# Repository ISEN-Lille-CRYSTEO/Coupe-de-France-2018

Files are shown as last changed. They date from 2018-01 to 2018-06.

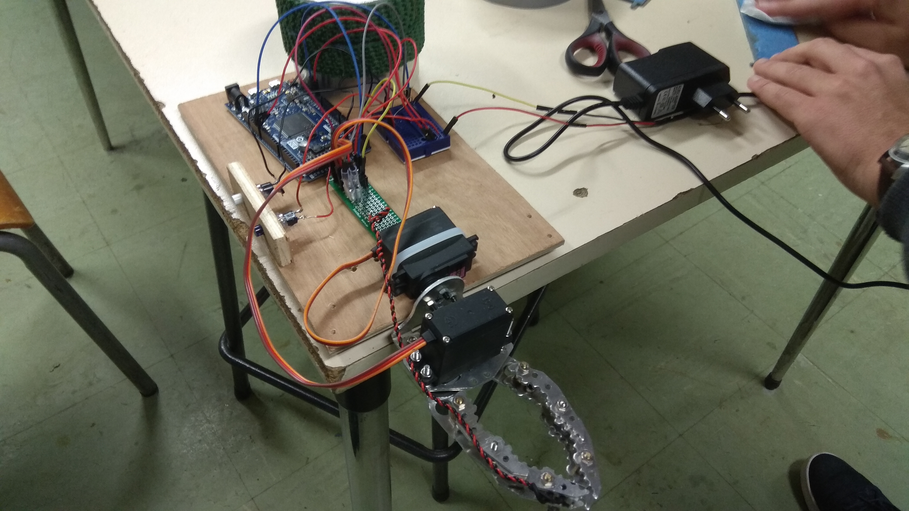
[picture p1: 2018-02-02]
pince/proto_pince.jpg

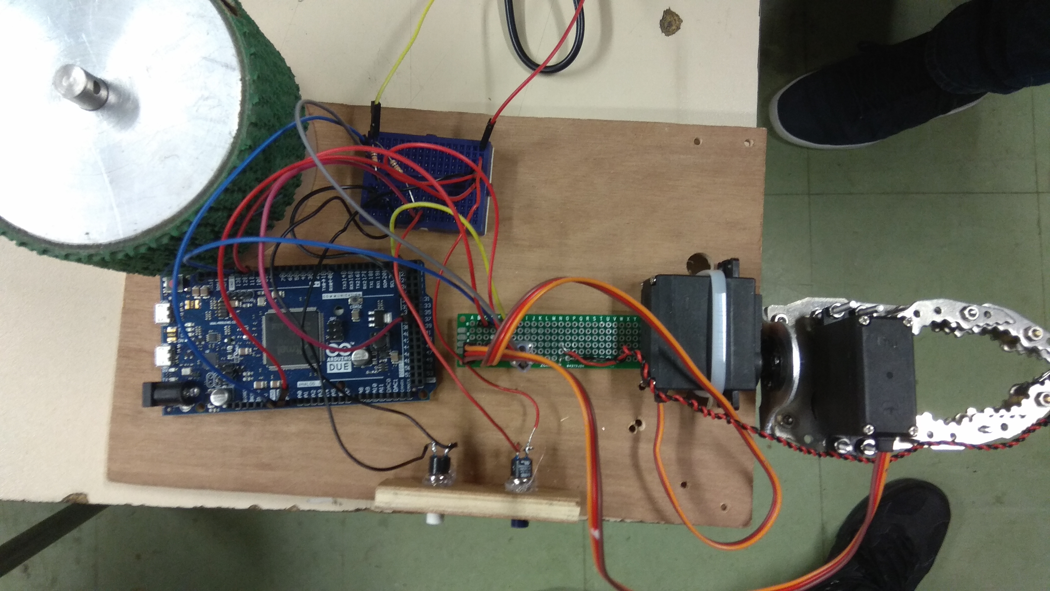
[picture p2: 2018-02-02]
pince/vu_dessus_proto_pince.jpg

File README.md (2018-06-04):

# Coupe de France de robotique 2018

## La fine équipe
### chargé de projet
&nbsp;&nbsp;&nbsp;&nbsp;  Gilou
### vice chargé de projet
&nbsp;&nbsp;&nbsp;&nbsp;  Thibault

### Electronique 
&nbsp;&nbsp;&nbsp;&nbsp;  Matthieu *2
  
### Informatique
&nbsp;&nbsp;&nbsp;&nbsp;  Thibault
&nbsp;&nbsp;&nbsp;&nbsp;  Brice

### Mecanique
&nbsp;&nbsp;&nbsp;&nbsp;  Junior
  
### Communication
&nbsp;&nbsp;&nbsp;&nbsp;  Victor

### Liens Crystéo
&nbsp;&nbsp;&nbsp;&nbsp;  Gautier

## Robot principal

Notre robot principal doit être capable de réaliser les modules suivants :

| Nom du module | Priorité |
|---|---|
|Asservissement|Haute|
|Ramassage de cubes |Basse|
|Funny action |Moyenne|

## Robot secondaire

Nous allons avoir un robot secondaire. La base mobile sera fournis par Louis Malbranque

| Nom du module | Priorité | Avancement |
|---|---|---|
|Déplacment| haute | presque fini |
|Ramassage de boules |Moyenne|null|
|Tri par couleur |Basse|null|

## Panneau domotique
 
A noter que les fichier du PCB du moteur on été changé par rapport aux driver actuels et que la carte de la due est a refaire et date de l'année précédente

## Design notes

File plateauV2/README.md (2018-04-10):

# Bouton
  - pinTrigger 31

# Pins roues

## Pin pince
- pinControllepince 8
- pinControllerotor 9
- pinCapteurbouton 7

## Roue codeuse
- encodeuseGaucheAvant 13
- encodeuseGaucheArriere 12
- encodeuseDroiteAvant 11
- encodeuseDroiteArriere 10

## CONNECTEUR
-  puissanceDroit 6
-  puissanceGauche 3
-  marcheAvantMoteurGauche 22
-  marcheArriereMoteurGauche 23
-  marcheAvantMoteurDroit 52
-  marcheArriereMoteurDroit 53

## CONSTANTES
-  Max 255 // vitesse null, 0 %
-  Min 200 // vitesse de croissière, 25 %
-  diametreRoueCodeuse 0.05228 // 52,28mm
-  diametreRoueMotor 0.285 //285mm
-  nombreTicksPour1TourDeRoue 1250
-  Pi 3.14159
-  perimetreRoueCodeuse diametreRoueCodeuse*Pi
-  demitour (Pi*diametreRoueMotor)/2 // divisé par deux pour un quart de tour

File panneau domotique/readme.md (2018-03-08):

# Panneau domotique

On va ici lire des valeurs tels que la température, la luminosité et autre
pour l'afficher sur un raspberrry avec un ecran

la lecture des valeurs se fait sur une arduino qui va lire les donnée en analogique et les transmettre au raspberry par le port serie.

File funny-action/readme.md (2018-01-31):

# Here files about the funny action

printing files are open, I export .stl for printing and .fcstd for editing
.fcstd can be open with FreeCad and stl with any 3D program

We choose to make the funny action indépendant from the system so it was pic managed
1 digital pin up to lauch else defaut réarm position

the pic is a *pic 16f690*
the RB6 is the entry
the RB4 is the output

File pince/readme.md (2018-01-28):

# here files about the pince

The pince is simple to use :

-	plug 5V and GND 
-	plug both servo on dédicated slot
-	connect the three controles pins to the arduino
-	link in the program
-	use it

I add to the pince a captor for detect when it grab something, the function is autograb()

We dont have already etablish contectic and code for move up and down the pince but we will work on

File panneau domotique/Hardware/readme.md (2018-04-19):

# PANNEAU DOMOTIQUE

Ici les fichier pour les PCB du panneau domotique

Les fichiers sont a ouvrir avec altium designer 

## Composants 

 - DHT 11 Température humidité
 - Photo resistance luminosité
 - Arduino nano reception des données
 - Raspberry

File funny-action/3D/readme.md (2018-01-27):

# here 3D files

.stl can be open on online interface
.fcstd can be open with freeCad

Certains fichier viennes de l'ancien repository Coupe de france (cf mes repository)

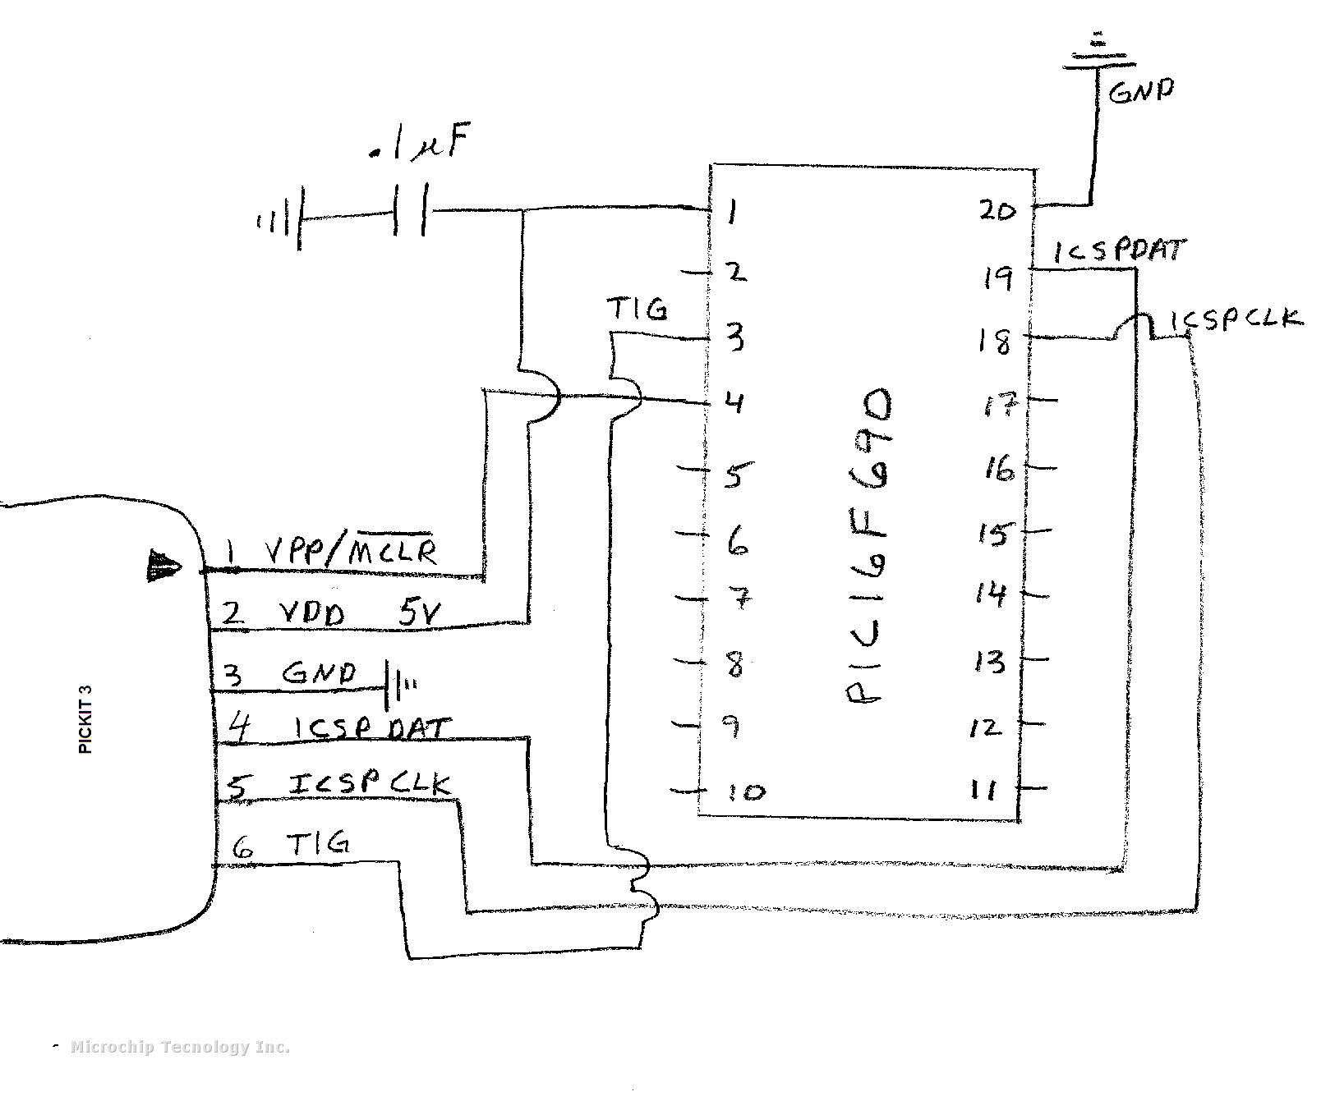
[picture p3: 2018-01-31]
funny-action/pic/branchement_pickit3.jpeg

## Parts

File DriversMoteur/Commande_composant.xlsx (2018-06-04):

Bon de Commande
Nom des étudiants: |  | Arthur Duytschaever
N-poste | Fournisseur | Quantité | U.D.V | Désignation | Référence | Prix en €
1 | Farnell | 2 | 1 | STK681-360-E Motor Driver | 2424510 | 4.9
1 | Farnell | 2 | 1 | HCPL-090J-000E Isolateur numérique | 1611323 | 11.57
 |  |  |  |  | Total H.T. | 32.94

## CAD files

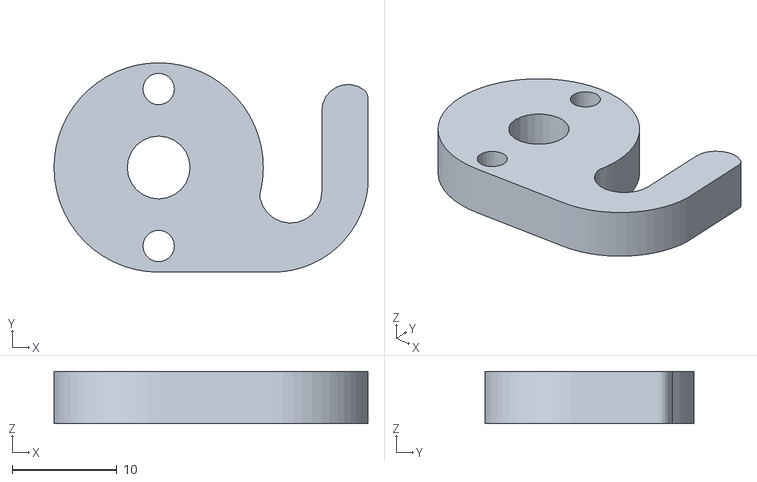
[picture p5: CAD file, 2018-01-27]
funny-action/3D/acroche.stl
30.0 x 20.0 x 5.00

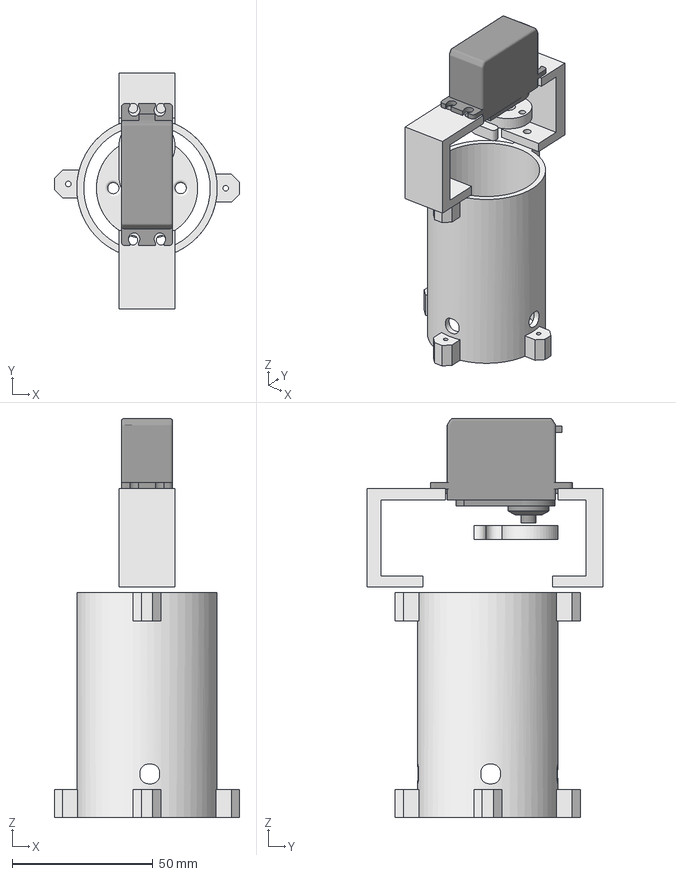
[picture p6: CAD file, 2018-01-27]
funny-action/3D/Funny action.fcstd
66.0 x 84.0 x 142.0 mm
propulseur
fixation
Servo
acroche
propulseurV3.

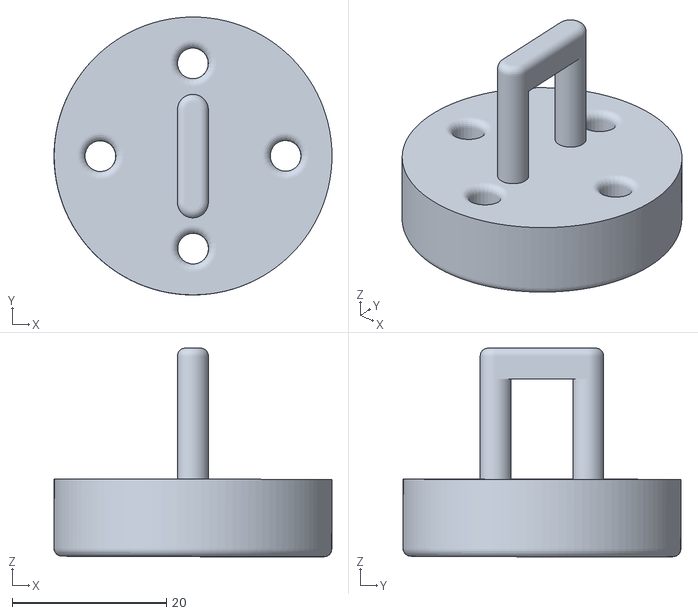
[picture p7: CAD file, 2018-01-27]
funny-action/3D/propulseurV3..stl
36.0 x 36.0 x 27.1

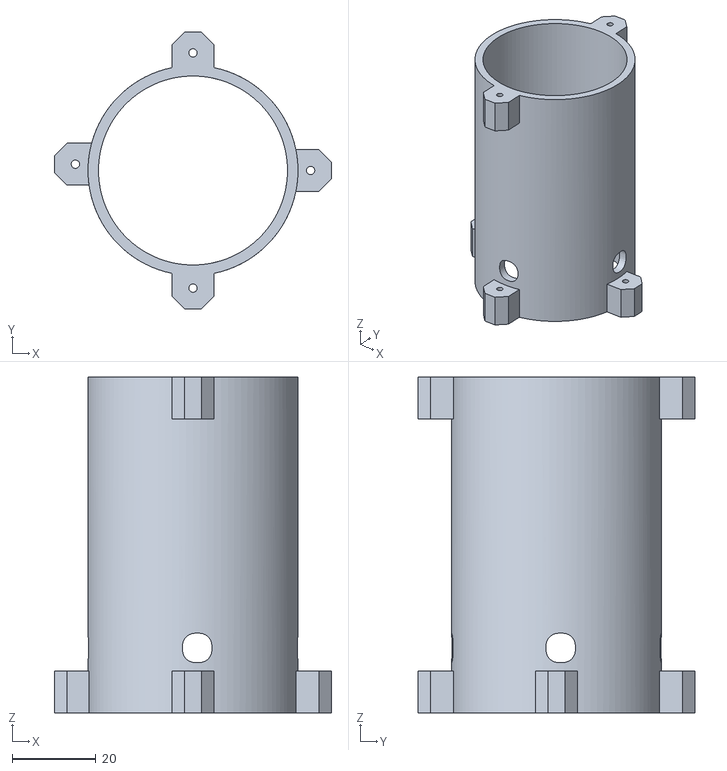
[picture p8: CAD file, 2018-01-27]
funny-action/3D/cylindre_propulseur.stl
66.0 x 66.0 x 80.0

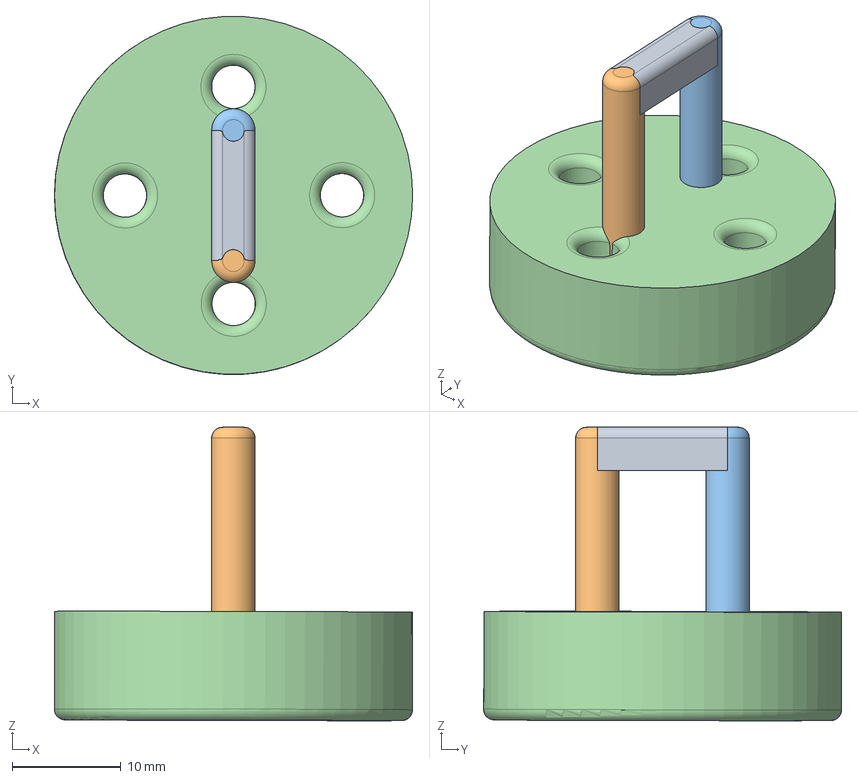
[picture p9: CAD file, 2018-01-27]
funny-action/3D/projeteurV3.fcstd
33.0 x 33.0 x 27.0 mm
base001

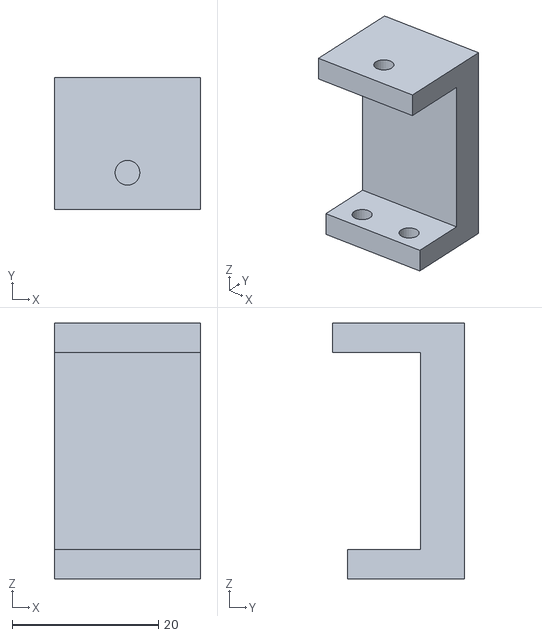
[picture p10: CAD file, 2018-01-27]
funny-action/3D/fixation_servo_courte.stl
20.0 x 18.0 x 35.0

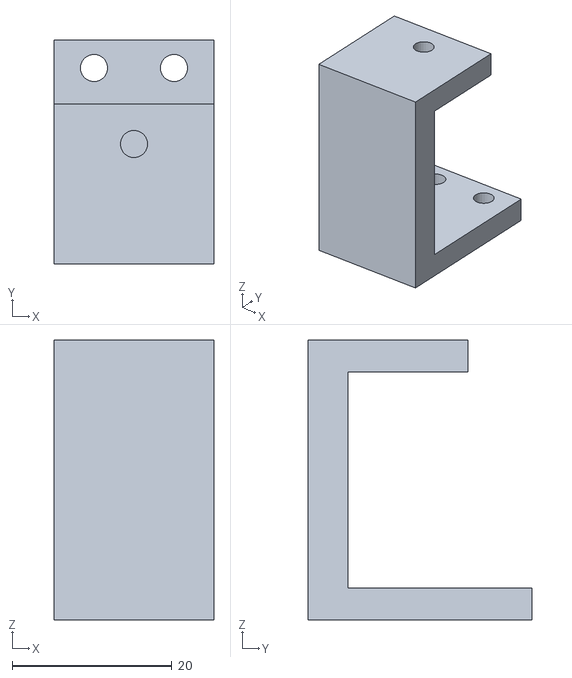
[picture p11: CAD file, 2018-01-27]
funny-action/3D/fixation_servo_longue.stl
20.0 x 28.0 x 35.0

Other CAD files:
funny-action/3D/funny action.stl

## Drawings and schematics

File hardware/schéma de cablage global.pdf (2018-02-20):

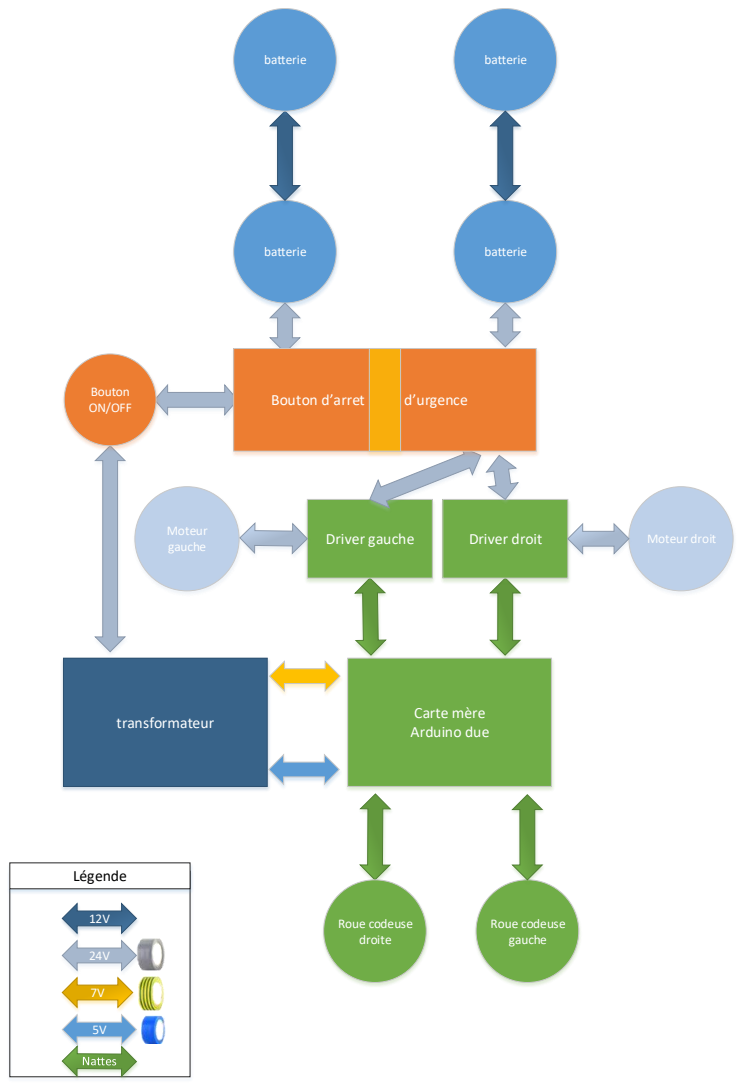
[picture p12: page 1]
Carte mère Arduino due; Légende; Driver droit; Moteur droit; transformateur; batterie; Driver gauche; Roue codeuse droite; Moteur gauche; Roue codeuse gauche; Bouton d arret; d urgence; Bouton ON/OFF

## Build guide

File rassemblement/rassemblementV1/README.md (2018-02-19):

=== Roue codeuse ===
#define encodeuseGaucheAvant 13 //encodeur gauche A
#define encodeuseGaucheArriere 12 //encodeur gauche B
#define encodeuseDroiteAvant 11 //encodeur droit A
#define encodeuseDroiteArriere 10 //encodeur droit B

//=== CONNECTEUR ===
#define puissanceDroit 6 // puissance du moteur droit
#define puissanceGauche 3 // puissance du moteur gauche
#define marcheAvantMoteurGauche 22 // position avancer
#define marcheArriereMoteurGauche 23 // position reculer
#define marcheAvantMoteurDroit 52 // position avancer
#define marcheArriereMoteurDroit 53 // position reculer

//=== CONSTANTES ===
#define Max 255 // vitesse null, 0 %
#define Min 200 // vitesse de croissière, 25 %
#define diametreRoueCodeuse 0.05228 // 52,28mm
#define diametreRoueMotor 0.285 //285mm
#define nombreTicksPour1TourDeRoue 1250
#define Pi 3.14159
#define perimetreRoueCodeuse diametreRoueCodeuse*Pi
#define demitour (Pi*diametreRoueMotor)/2 // divisé par deux pour un quart de tour

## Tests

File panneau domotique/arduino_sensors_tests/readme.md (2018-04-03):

Programmes arduino permettant de proceder a des tests pour les capteurs DHT11 (Temperature / humidite) et KY-018 (Lumiere)

Le programme permettant de renvoyer toutes les mesures est "DomotiqueSensors"

Libraries:

- DHT Sensor
https://github.com/adafruit/DHT-sensor-library
- Adafruit Sensor
https://github.com/adafruit/Adafruit_Sensor

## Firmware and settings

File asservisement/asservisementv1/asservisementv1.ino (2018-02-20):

//=== CONNECTEUR ===
#define puissanceDroit 6 // puissance du moteur droit
#define puissanceGauche 3 // puissance du moteur gauche
#define funnyAction 33 // Controlleur de lanceur
#define marcheAvantMoteurGauche 22 // position avancer
#define marcheArriereMoteurGauche 23 // position reculer
#define marcheAvantMoteurDroit 52 // position avancer
#define marcheArriereMoteurDroit 53 // position reculer
#define encodeuseGaucheAvant 13 //encodeur gauche A
#define encodeuseGaucheArriere 12 //encodeur gauche B
#define encodeuseDroiteAvant 11 //encodeur droit A
#define encodeuseDroiteArriere 10 //encodeur droit B
//=== CONSTANTES ===
#define diametreRoueCodeuse 0.05228 // 52,28mm
#define diametreRoueMotor 0.285 //285mm
#define nombreTicksPour1TourDeRoue 1250
#define Pi 3.14159
#define perimetreRoueCodeuse diametreRoueCodeuse*Pi
#define demitour (Pi*diametreRoueMotor)/2 // divisé par deux pour un quart de tour
#define distancepafaire 1 // 1 metres
#define direction 0 // 0 = droite, 1 = gauche
//=== VARIABLE ===
unsigned int tick_codeuse_R = 0;   // Compteur de tick de la codeuse
unsigned int tick_codeuse_L = 0;   // Compteur de tick de la codeuse
unsigned int valL = 200;
unsigned int valR = 202;
double compte = 0;
int diff = 0;
int r = 0;

void setup() {
	Serial.begin(115200);   // Initialisation port COM
//=== FunnyAction ===
	pinMode(funnyAction,OUTPUT);
	digitalWrite(funnyAction,LOW);
//=== Moteur ===
	pinMode(puissanceDroit,OUTPUT);
 	pinMode(puissanceGauche,OUTPUT);
 	pinMode(marcheAvantMoteurDroit,OUTPUT);
 	pinMode(marcheArriereMoteurDroit,OUTPUT);
 	pinMode(marcheAvantMoteurGauche,OUTPUT);
 	pinMode(marcheArriereMoteurGauche,OUTPUT);
 	pinMode(encodeuseGaucheAvant,INPUT);
 	pinMode(encodeuseGaucheArriere,INPUT);
 	pinMode(encodeuseDroiteAvant,INPUT);
 	pinMode(encodeuseDroiteArriere,INPUT);
//=== Attachement au fonction ===
 	attachInterrupt(encodeuseGaucheAvant, compteur_tick_L, RISING);
 	attachInterrupt(encodeuseDroiteAvant, compteur_tick_R, RISING);
//=== Allumage des motor ===
 	digitalWrite(marcheAvantMoteurDroit,LOW);
 	digitalWrite(marcheArriereMoteurDroit,LOW);
 	digitalWrite(marcheAvantMoteurGauche,LOW);
 	digitalWrite(marcheArriereMoteurGauche,LOW);
 	analogWrite(puissanceDroit,valR);
 	analogWrite(puissanceGauche,valL);
//=== FunnyAction by ....
 	delay(5000);
 	digitalWrite(funnyAction,HIGH);
 	tick_codeuse_R = 0;
 	tick_codeuse_L = 0;
}

void loop() {
//=== Démarrage des moteur ===
	digitalWrite(marcheAvantMoteurDroit,HIGH);
	digitalWrite(marcheAvantMoteurGauche,HIGH);
 	if(calculVitesse(tick_codeuse_R) > calculVitesse(tick_codeuse_L))
 		compte = calculVitesse(tick_codeuse_R);
 	else
 		compte = calculVitesse(tick_codeuse_L);

//=== rotation du roboot ===
   	compte = rotation(direction,compte,distancepafaire);

//=== Avancement du roboot ===
   	avancement(calculVitesse(tick_codeuse_R) -  calculVitesse(tick_codeuse_L)); // fait avancer le reboot tout droit
}

void compteur_tick_R(){
  tick_codeuse_R++;
}
void compteur_tick_L(){
 	tick_codeuse_L++;
}

//Si il tourne a gauche, gauche va tro vite
void avancement(int diff){
 	if(diff > 0){//la roue codeuse a gauche va tro vitee
 		valL += 1;
   	if(valL > 255)
    	valL = 255;
 	}
 	else if(diff < 0){//la roue codeuse a droite va tro vitee
   		valR += 1;
   	if(valR > 255)
     	valR = 255;
 	}
 	else {//Si non vitesse constance
   		valL = 200;
   		valR = 202;
 	}
 	analogWrite(puissanceDroit,valR);
 	analogWrite(puissanceGauche,valL);
 	delay(10);
}

int rotation(bool valeur,int compte,int distance){
	if(compte >= distance){
 		valL = 225;// On diminue la vitesse des roue.
 		valR = 225;
 		analogWrite(puissanceDroit,valR);
 		analogWrite(puissanceGauche,valL);

 		digitalWrite(marcheAvantMoteurGauche,!valeur);
 		digitalWrite(marcheAvantMoteurDroit,valeur);
 		delay(50); // on inverse un des 2 motor.
 		digitalWrite(marcheArriereMoteurGauche,valeur);
 		digitalWrite(marcheArriereMoteurDroit,!valeur);

 		tick_codeuse_L = 0;
 		tick_codeuse_R = 0;
 		while(calculVitesse(tick_codeuse_R) <= demitour && calculVitesse(tick_codeuse_L) <= demitour){
 			Serial.print(demitour);
 			Serial.print(" <= ");
			Serial.println(calculVitesse(tick_codeuse_R));
 		}

 		digitalWrite(marcheArriereMoteurGauche,LOW);
 		digitalWrite(marcheArriereMoteurDroit,LOW);
 		delay(50);// on remet les 2 motor en marche avant.
 		digitalWrite(marcheAvantMoteurGauche,HIGH);
 		digitalWrite(marcheAvantMoteurDroit,HIGH);

 		tick_codeuse_L = 0;
 		tick_codeuse_R = 0;
 		return 0;

	}else{
		return compte;
	}
}

double calculVitesse(unsigned int tick_codeuse){
 	double nombre_tours = (double) tick_codeuse / (double) nombreTicksPour1TourDeRoue;
 	double metre_parcourue = (double) nombre_tours * (double) perimetreRoueCodeuse; // en mêtres
 	return (double) metre_parcourue;
}

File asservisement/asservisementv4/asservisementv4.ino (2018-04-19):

#include "asservisementv4.h"

//=== CONSTANTES ===
#define encodeuseGaucheAvant 13 //encodeur gauche A
#define encodeuseDroiteAvant 11 //encodeur droit A
#define encodeuseGaucheArriere 12 //encodeur gauche A
#define encodeuseDroiteArriere 10 //encodeur droit A
// === Variable ===
double distancepafaire = 0.5; // 1 metre
double degre = 180; // 180 degree soit un demi-tour
int distance = 0; // compteur de metre qu'il fait
int sens = 1; // 1 = marche Avant , 0 = Marche arriere
int direction = 0; // 0 = droite, 1 = gauche
CDF_asservisement asservisement;

void setup() {
	Serial.begin(115200);   // Initialisation port COM
	Serial.print("Début");
	/* === Attachement au fonction === */
 	asservisement = CDF_asservisement(13,12,11,10,6,3,22,23,52,53);
 	attachInterrupt(digitalPinToInterrupt(encodeuseGaucheAvant), [&](){asservisement.compteur_tick_L1();}, RISING);
 	attachInterrupt(digitalPinToInterrupt(encodeuseDroiteAvant), [&](){asservisement.compteur_tick_R1();}, RISING);
	attachInterrupt(digitalPinToInterrupt(encodeuseGaucheArriere), [&](){asservisement.compteur_tick_L2();}, RISING);
 	attachInterrupt(digitalPinToInterrupt(encodeuseDroiteArriere), [&](){asservisement.compteur_tick_R2();}, RISING);
}

void loop() {
	Serial.println(asservisement.avancement(sens));
	Serial.println(distancepafaire);
	while(asservisement.avancement(sens) <= distancepafaire){
		delay(1);
	}
  asservisement.rotation(degre);
}

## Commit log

2018-01-27 ajout des fichier 3d
    [Funny action.fcstd, cylindre_propulseur.stl, fixation_servo_courte.stl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]
2018-01-27 move 3D files
    [Funny action.fcstd, cylindre_propulseur.stl, fixation_servo_courte.stl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]
2018-01-27 add files 3D
    ajout d'un modele complet de la funny action ainsi que des pieces manquantes
    [Funny action.fcstd, acroche.stl, funny action.stl]
2018-02-01 add a demo programme for the pince
    need a button and a potar
2018-02-15 ajout de documentation
2018-02-19 Asservisement par des fonction
2018-02-19 correction des fonction d'asservissement
    [asservisement v2.h, asservisement v2.ino]
2018-02-20 Débug des asservisement
2018-02-20 rajout de rassemblement des fonction fini
2018-03-13 creation d'un plateauV1
2018-03-13 debug plateauV1
2018-03-13 ajout d'un code arduino pour tester le serial
2018-03-13 ajout de la gestion de l'absence de port série
2018-03-20 plateau + capteur
2018-03-21 plateau correction de bug
    [capteur.cpp, plateauV1.cpp, plateauV1.ino]
2018-03-27 Plateau -> capteur + contournement
2018-03-29 correction du bug de detection a tester
    [plateauV1.cpp, plateauV1.ino]
2018-04-03 V2 plateau en création + maxi arguement
2018-04-05 corrections pixel ready de l'image
2018-04-05 correction des bug
2018-04-10 plateau with pince !! in English plz
2018-04-18 ajout du PCB panneau domotique
    [CDF_sensor.PrjPcb, CDF_sensor_pcb.PcbDoc, DHT11.PcbLib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]
2018-04-19 départ finie + correction du asservisement
    [asservisementv4.cpp, asservisementv4.ino, plateauV2.cpp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]
2018-06-04 ajout du driver moteur et du shield due
    [BMI_HEARDER_4mm.PcbLib, BMI_HEARDER_4mm.SchLib, BarLed.SchDoc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]
